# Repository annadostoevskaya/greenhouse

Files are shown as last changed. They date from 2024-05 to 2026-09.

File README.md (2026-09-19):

# FGL-GH-24: Embedded Telemetry & Automated Observability Platform







An industrial-grade IoT telemetry and environmental monitoring system bridging physical embedded microcontroller hardware with modern Linux container infrastructure and real-time observability pipelines.

---

## 1. System Architecture

```mermaid
graph LR
    subgraph EdgeHardware ["Physical Edge Hardware"]
        SENSORS["Environmental Sensors<br/>(DHT22, Soil, Light, DS18B20)"] --> MCU["Embedded Microcontroller<br/>(AVR / C++ Firmware)"]
        MCU --> W5100["W5100 Ethernet Controller<br/>(SPI Bus Interface)"]
    end

    subgraph NetworkLink ["Transport Layer"]
        W5100 -->|"Direct Ethernet Link (10/100 Mbps)<br/>Subnet: 10.0.0.0/24"| ETH["Linux Host Interface<br/>(enp0s25 / Static IP)"]
    end

    subgraph LinuxHost ["Host Observability Stack (Docker Compose)"]
        ETH --> NGINX["Nginx Edge Ingress Proxy<br/>(:8080)"]
        NGINX --> JSON_EXP["Prometheus JSON Exporter<br/>(:7979)"]
        JSON_EXP --> PROM["Prometheus Time-Series TSDB<br/>(Scrape Interval: 15s)"]
        PROM --> GRAFANA["Grafana Analytics & Dashboards<br/>(:3000)"]
    end
```

---

## 2. Key Engineering Highlights

* **Bare-Metal Hardware & Firmware:**
  * Embedded C++ firmware built with optimized memory footprint using `avr-libc` and `PROGMEM` flash storage for static web assets.
  * Hardware communication via SPI interface to a dedicated W5100 hardware TCP/IP controller.
  * Fault-tolerant serial monitoring and telemetry streaming (`/dev/ttyUSB0` at 9600 baud).

* **Deterministic Networking:**
  * Direct crossover Ethernet interconnect between edge controllers and host processing nodes (`10.0.0.0/24`).
  * Dedicated low-latency packet transit isolated from public gateway networks.

* **Cloud-Native Observability Pipeline:**
  * Fully declarative `docker-compose` orchestration with isolated internal bridge networks and non-root security contexts (`UID: 65534`).
  * End-to-end telemetry ingestion using `prometheuscommunity/json-exporter` to transform raw microcontroller sensor payloads into Prometheus metric format.
  * Persistent Grafana visualization and Prometheus TSDB storage with WAL integrity.

* **Automated CI/CD & Documentation:**
  * Integrated `.gitlab-ci.yml` pipeline automating Doxygen API documentation generation and build validation.

---

## 3. Quick Start & Deployment

### Hardware Network Setup
Establish the direct link interface on the host machine:
```bash
sudo ip addr add 10.0.0.1/24 brd + dev enp0s25
sudo ip link set enp0s25 up
```

### Serial Diagnostics
To access the real-time hardware telemetry feed:
```bash
stty -F /dev/ttyUSB0 raw 9600 && cat /dev/ttyUSB0
```

### Starting the Observability Stack
```bash
# Clone the repository
git clone https://github.com/annadostoevskaya/greenhouse.git
cd greenhouse

# Launch the containerized monitoring stack
docker compose up -d

# Verify services
docker compose ps
```

* **Web Ingress:** `http://localhost:8080`
* **Prometheus Targets:** `http://localhost:9090`
* **Grafana Dashboard:** `http://localhost:3000` (Default: `admin` / `admin`)

---

## 4. Repository Structure

```text
├── firmware/              # Microcontroller C++ source code & hardware drivers
├── docker/
│   ├── json-exporter.yml  # Metric extraction patterns for sensor JSON
│   └── prometheus.yml     # Scrape targets and TSDB retention configurations
├── docker-compose.yml     # Multi-container orchestration (Nginx, Prometheus, Grafana)
├── deploy.sh              # Host automation deployment script
├── stress.sh              # Network throughput & telemetry load testing utility
└── .gitlab-ci.yml         # Automated CI/CD pipeline definition
```

---

## 5. License & Compliance
This project is open-source software licensed under the MIT License. It represents independent hardware/software research and development.

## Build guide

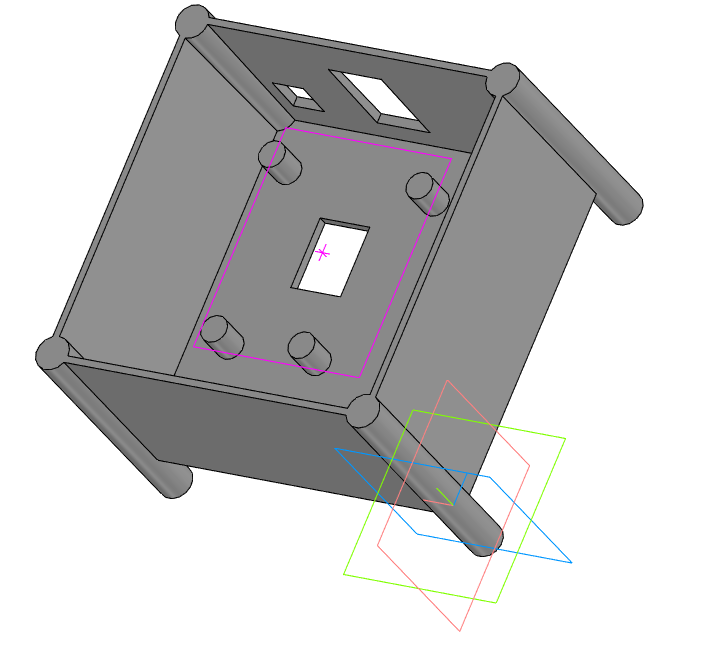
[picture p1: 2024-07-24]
manual/img/housing_1.png

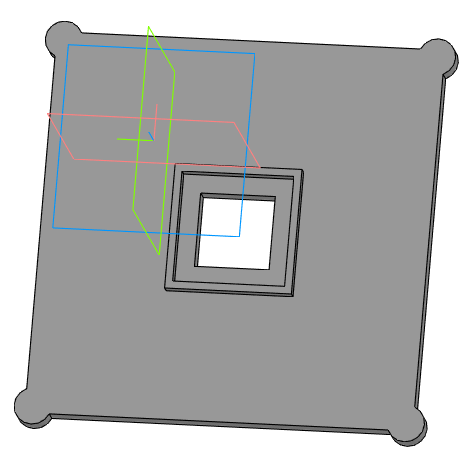
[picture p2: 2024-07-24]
manual/img/housing_2.png

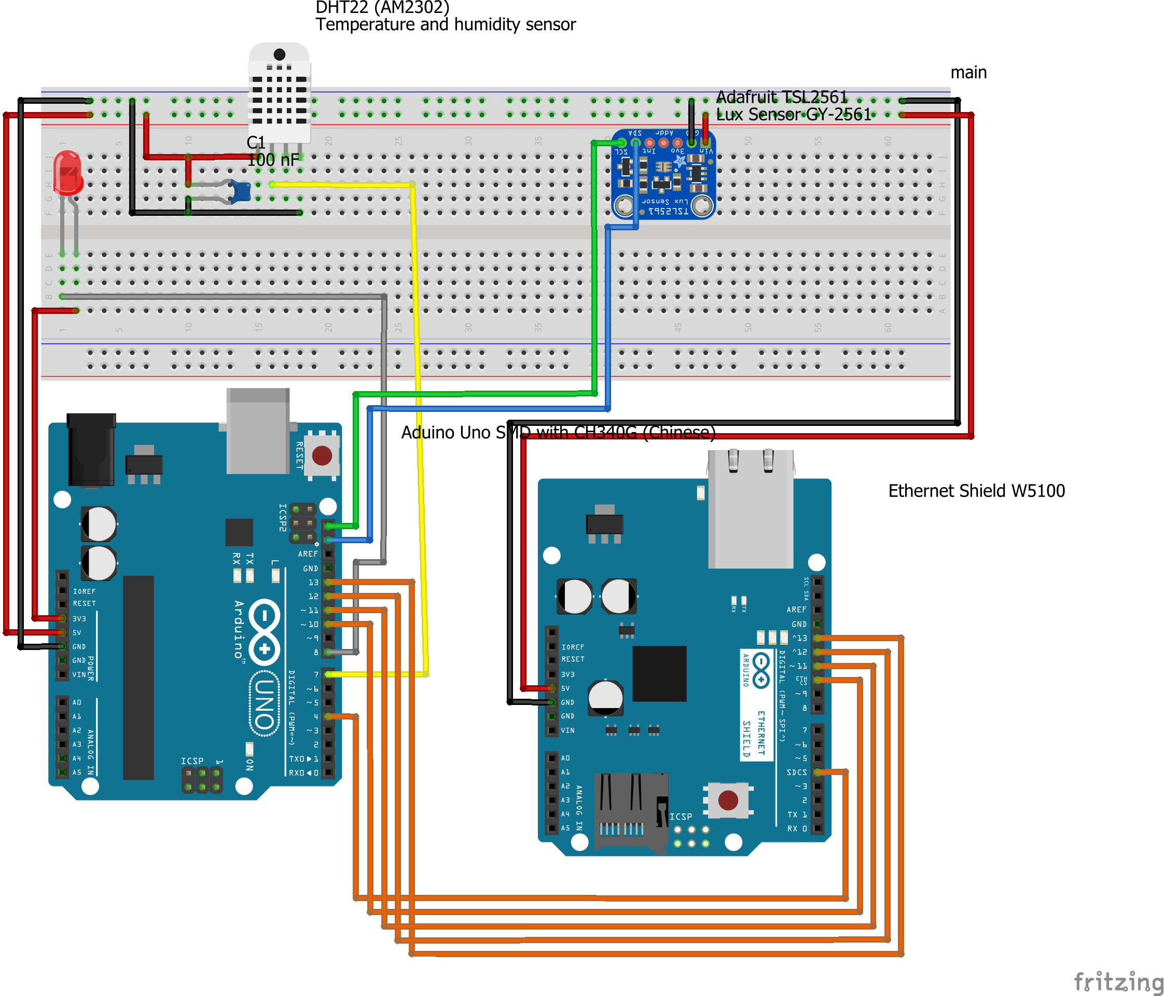
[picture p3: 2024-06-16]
manual/img/Layout_bb.png

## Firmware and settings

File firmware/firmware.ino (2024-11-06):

/*
 * Author: @github.com/annadostoevskaya
 * Filename: firmware.ino
 * Created: 12 May 2024 2:39:28 AM
 * Last Update: 12 May 2024 2:39:50 AM
 */

#include <stdint.h>

#include <Wire.h>
#include <SPI.h>
#include <Adafruit_Sensor.h>
#include <Adafruit_TSL2561_U.h>
#include <DHT.h>
#include <Ethernet.h>
#include <SD.h>

#include "ini.h"
#include "NoCString.h"
#include "parsers.h"

Adafruit_TSL2561_Unified g_TSL2561 = Adafruit_TSL2561_Unified(TSL2561_ADDR_FLOAT, 0x752);
DHT g_DHT = DHT(0x7, DHT22);
/** \brief \link g_Server \endlink up server on Arduino Uno board, listen port 80. */
EthernetServer g_Server = EthernetServer(80);

void setup()
{
  /**************************** Basic IO setup ***************************/
  setup_speaker();
  Serial.begin(9600);

  /**************************** Setup tsl2561 ****************************/
  if (!g_TSL2561.begin())
  {
    Serial.println(F("Error: No TSL2561 detected... Check your wiring or I2C ADDR!"));
    for (;;) { speaker(2000); }
  }

  g_TSL2561.enableAutoRange(true);
  g_TSL2561.setIntegrationTime(TSL2561_INTEGRATIONTIME_101MS);

  /**************************** Setup dht11 ******************************/
  g_DHT.begin();

  /**************************** Setup SD card ****************************/
  Serial.println(F("Info: Intializing SD card..."));
  if (!SD.begin(4))
  {
    Serial.println(F("Error: SD card initialization failed!"));
    for (;;) { speaker(2000); }
  }

  /**************************** Reading config ***************************/
  Serial.println(F("Info: Reading config file..."));
  if (!SD.exists(F("CONFIG.INI")))
  {
    Serial.println(F("Error: Can't find config file!"));
    for (;;) { speaker(500); }
  }

  File f_Config = SD.open(F("CONFIG.INI"));
  size_t cfg_size = f_Config.size();
  char *cfg_content = (char *)malloc(f_Config.size()) + 1;
  cfg_content[cfg_size] = '\0';
  if (!cfg_content)
  {
    Serial.println(F("Error: Failed to allocate memory!"));
    for (;;) { speaker(500); }
  }

  if (f_Config.read(cfg_content, cfg_size) == -1)
  {
    Serial.println(F("Error: Failed to read config file."));
    for (;;) { speaker(500); }
  }

  Serial.println("CONFIG.INI:");
  Serial.println(cfg_content);

  f_Config.close();

  NoCString network_mac     = ini_get_value(cfg_content, "network", "MAC");
  NoCString network_ip      = ini_get_value(cfg_content, "network", "IP");
  NoCString network_dns     = ini_get_value(cfg_content, "network", "DNS");
  NoCString network_gateway = ini_get_value(cfg_content, "network", "GATEWAY");
  NoCString network_subnet  = ini_get_value(cfg_content, "network", "SUBNET");

  /**************************** Setup Ethernet ***************************/
  Serial.println(F("Info: Intializing Ethernet..."));

  uint8_t mac[6];
  uint8_t ip[4];
  uint8_t dns[4];
  uint8_t gateway[4];
  uint8_t subnet[4];

  if (parse_mac(network_mac, mac)
    && parse_ip(network_ip, ip)
    && parse_ip(network_dns, dns)
    && parse_ip(network_gateway, gateway)
    && parse_ip(network_subnet, subnet))
  {
    Ethernet.begin(mac, ip, dns, gateway, subnet);

    Serial.print(F("Info: MAC address: "));
    Ethernet.MACAddress(mac);
    for (int i = 0; i < 6; i++) {
      Serial.print(mac[i], HEX);
      if (i < 5) {
        Serial.print(':');
      }
    }
    Serial.println();

    Serial.print(F("Info: IP address: "));
    Serial.println(Ethernet.localIP());
    Serial.print(F("Info: gateway IP: "));
    Serial.println(Ethernet.gatewayIP());
    Serial.print(F("Info: subnet: "));
    Serial.println(Ethernet.subnetMask());
    Serial.print(F("Info: DNS: "));
    Serial.println(Ethernet.dnsServerIP());
  }
  else
  {
    Serial.println(F("Error: Failed to parse MAC or IP/DNS/GATEWAY/SUBNET address"));
    for (;;) { speaker(500); }
  }
}

void loop()
{
  EthernetClient cli = g_Server.available();

  if (cli)
  {
    off_speaker();
    Serial.println(F("Info: Client available, quantities scanning..."));
    sensors_event_t event;
    g_TSL2561.getEvent(&event);
    float h = g_DHT.readHumidity();
    float t = g_DHT.readTemperature();

    bool eof = true;

    while (cli.connected())
    {
      if (cli.available())
      {
        char c = cli.read();
        // Serial.print(c);

        if (c == '\n' && eof)
        {
          Serial.println(F("Info: Sending..."));
          cli.println(F("HTTP/1.1 200 OK"));
          cli.println(F("Content-Type: application/json"));
          cli.println(F("Connection: close"));
          cli.println();
          cli.print(F("{\"H\":"));
          cli.print(h);
          cli.print(F(",\"T\":"));
          cli.print(t);
          cli.print(F(",\"L\":"));
          cli.print(event.light);
          cli.print('}');
          break;
        }

        if (c == '\n')
        {
          eof = true;
        }
        else if (c != '\r')
        {
          eof = false;
        }
      }
    }

    cli.flush();
    on_speaker();
    cli.stop();
  }
}

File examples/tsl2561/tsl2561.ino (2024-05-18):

/*
 * Author: @github.com/annadostoevskaya
 * Filename: tsl2561.ino
 * Created: 18 May 2024 15:52:28 AM
 * Last Update: 18 May 2024 15:52:50 AM
 *
 * Description: "Adafruit TSL2561"@1.1.2
 */

#include <Wire.h>
#include <Adafruit_Sensor.h>
#include <Adafruit_TSL2561_U.h>

Adafruit_TSL2561_Unified tsl = Adafruit_TSL2561_Unified(TSL2561_ADDR_FLOAT, 0x752);

void displaySensorDetails(void)
{
  sensor_t sensor;
  tsl.getSensor(&sensor);
  Serial.println("------------------------------------");
  Serial.print  ("Sensor:       "); Serial.println(sensor.name);
  Serial.print  ("Driver Ver:   "); Serial.println(sensor.version);
  Serial.print  ("Unique ID:    "); Serial.println(sensor.sensor_id);
  Serial.print  ("Max Value:    "); Serial.print(sensor.max_value); Serial.println(" lux");
  Serial.print  ("Min Value:    "); Serial.print(sensor.min_value); Serial.println(" lux");
  Serial.print  ("Resolution:   "); Serial.print(sensor.resolution); Serial.println(" lux");  
  Serial.println("------------------------------------");
  Serial.println("");
  delay(500);
}

void configureSensor(void)
{
  /* You can also manually set the gain or enable auto-gain support */
  // tsl.setGain(TSL2561_GAIN_1X);      /* No gain ... use in bright light to avoid sensor saturation */
  // tsl.setGain(TSL2561_GAIN_16X);     /* 16x gain ... use in low light to boost sensitivity */
  tsl.enableAutoRange(true);            /* Auto-gain ... switches automatically between 1x and 16x */
  
  /* Changing the integration time gives you better sensor resolution (402ms = 16-bit data) */
  tsl.setIntegrationTime(TSL2561_INTEGRATIONTIME_13MS);      /* fast but low resolution */
  // tsl.setIntegrationTime(TSL2561_INTEGRATIONTIME_101MS);  /* medium resolution and speed   */
  // tsl.setIntegrationTime(TSL2561_INTEGRATIONTIME_402MS);  /* 16-bit data but slowest conversions */

  /* Update these values depending on what you've set above! */  
  Serial.println("------------------------------------");
  Serial.print  ("Gain:         "); Serial.println("Auto");
  Serial.print  ("Timing:       "); Serial.println("13 ms");
  Serial.println("------------------------------------");
}

/**************************************************************************/
/*
    Arduino setup function (automatically called at startup)
*/
/**************************************************************************/
void setup(void) 
{
  Serial.begin(9600);
  Serial.println("Light Sensor Test"); Serial.println("");
  
  /* Initialise the sensor */
  //use tsl.begin() to default to Wire, 
  //tsl.begin(&Wire2) directs api to use Wire2, etc.
  if(!tsl.begin())
  {
    /* There was a problem detecting the TSL2561 ... check your connections */
    Serial.print("Ooops, no TSL2561 detected ... Check your wiring or I2C ADDR!");
    while(1);
  }
  
  /* Display some basic information on this sensor */
  displaySensorDetails();
  
  /* Setup the sensor gain and integration time */
  configureSensor();
  
  /* We're ready to go! */
  Serial.println("");
}

/**************************************************************************/
/*
    Arduino loop function, called once 'setup' is complete (your own code
    should go here)
*/
/**************************************************************************/
void loop(void)
{
  /* Get a new sensor event */ 
  sensors_event_t event;
  tsl.getEvent(&event);
 
  /* Display the results (light is measured in lux) */
  if (event.light)
  {
    Serial.print(event.light); Serial.println(" lux");
  }
  else
  {
    /* If event.light = 0 lux the sensor is probably saturated
       and no reliable data could be generated! */
    Serial.println("Sensor overload");
  }
  delay(250);
}

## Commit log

2024-04-13 feature: update README, SPI
2024-04-18 feature: update README, solve CH340G (drivers) problem
2024-05-12 feature: buggy dhcp connect
    [firmware.ino]
2024-05-12 fix: MAC address strange behaviour
    [firmware.ino]
2024-05-14 feature: ArduinoJson
2024-05-18 feature: Fritzing documentation
    [Layout.fzz]
2024-05-19 feature: Fritzing documentation 2
    [Layout.fzz]
2024-05-19 feature: Fritzing documentation, LED
    [Layout.fzz]
2024-05-28 feature: firmware/speaker and refactoring
    [Layout.fzz]
2024-05-28 fix: move documents to root
    [Layout.fzz]
2024-05-29 feature: fix NoCString (stupid mistake...) and parse_mac
    [firmware.ino]
2024-06-08 fix: MAC address printing
    [firmware.ino]
2024-06-08 fix: fix minor mistakes
    [Layout.fzz]
2024-06-08 fix: remove unsupported version of client
    [speaker.ino]
2024-06-13 feature: speaker, 2s - hardware error, 0.5s - config error
    [firmware.ino, speaker.ino]
2024-07-22 feature: remove license and write doxygen files
    [Layout.fzz]
2024-07-24 feature: todo list and housing page
2024-08-03 feature: stress test, set speaker as enabled and fix schema dox
    [speaker.ino]
2024-08-13 feature: proxy for arduino-cli
2024-08-13 feature: proxy for arduino-clit
2024-09-01 fix: proxy settings for arduino-cli

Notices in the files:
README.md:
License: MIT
